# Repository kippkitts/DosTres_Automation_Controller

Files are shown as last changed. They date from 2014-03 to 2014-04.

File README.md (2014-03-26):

DosTres_Automation_Controller
=============================

DosTres Automation

The [DosTres Automation Controller](http://kippkitts.com/collections/frontpage/products/dostres-automation-controller-kk-m-23) is a shield for the Arduino Uno that allows you to control a number of high power devices.  It carries motor drivers to power 2 brush DC motors at 40v/5A as well as 3 MOSFET load switches to control high load devices (solenoids, lights, pumps, etc.).  The DosTres also allows you to drive a stepper motor in place of the DC motors.  The Eagle files for this board can be found here.

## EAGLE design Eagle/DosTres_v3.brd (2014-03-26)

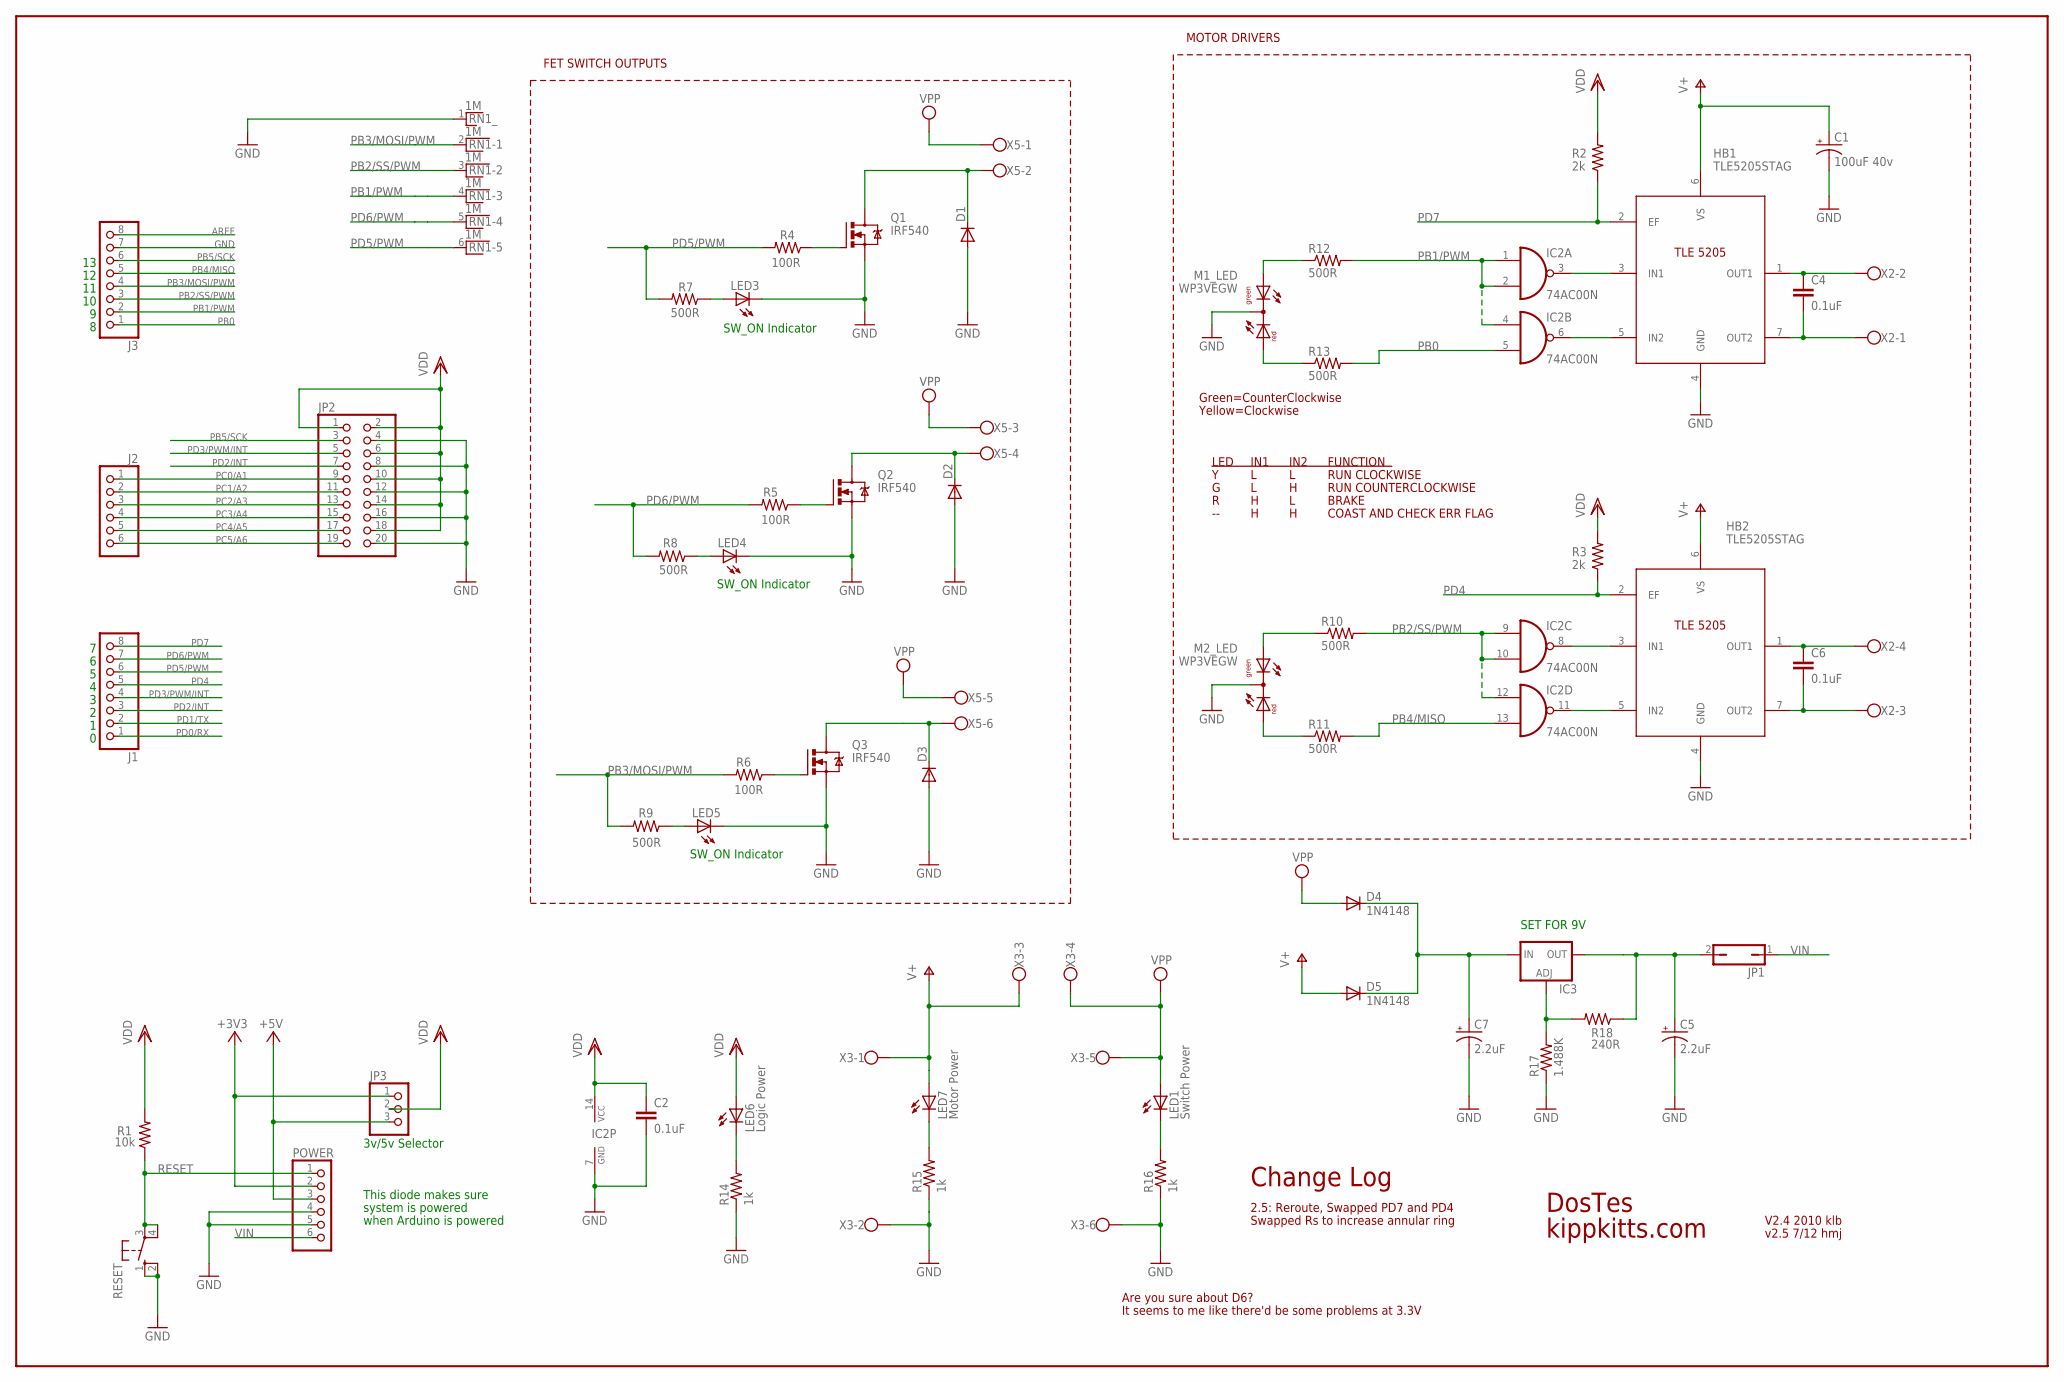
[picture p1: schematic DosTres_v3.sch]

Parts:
C1: 100uF 40v; E2,5-6E
C2, C4, C6: 0.1uF; CAP-PTH-SMALL-KIT
C5, C7: 2.2uF; CPOL-RADIAL-10UF-25V
D1, D2, D3: DIODE-1MMHOLED-7.5BH; D-7.5BH
D4, D5: 1N4148; D-7.5BH
HB1, HB2: TLE5205STAG; TO220-7-11
IC2: 74AC00N; DIL14
IC3: LM317TS; 317TS
J1, J3: PINHD-1X8; 1X08
J2: PINHD-1X6; 1X06
JP1: JP1Q; JP1
JP2: PINHD-2X10HAND; 2X10HAND
JP3: PINHD-1X3; 1X03
LED1: Switch Power; LED3MM
LED3, LED4, LED5: LED3MMX1MM3MM; LED3MM
LED6: Logic Power; LED3MM
LED7: Motor Power; LED3MM
M1_LED, M2_LED: WP3VEGW; DUOLED-A-3MM
POWER: PINHD-1X6; 1X06
Q1, Q2, Q3: IRF540; TO220BV
R1: 10k; 0207/2V
R2, R3: 2k; 0207/2V
R4, R5, R6: 100R; 0207/2V
R7, R8, R9, R10, R11, R12, R13: 500R; 0207/2V
R14, R15, R16: 1k; 0207/2V
R17: 1.488K; 0207/2V
R18: 240R; 0207/2V
RESET: 10-XX; B3F-10XX
RN1: 1M; RN-6
X2: W237-4
X3, X5: W237-6

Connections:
+3V3: JP3.1, POWER.2
+5V: JP3.3, POWER.3
AREF: J3.8
GND: C1.-, C2.2, C5.2 (-), C7.2 (-), D1.A, D2.A, D3.A, HB1.4 (GND), HB2.4 (GND), IC2.7 (GND), J3.7, JP2.4, JP2.8, JP2.12, JP2.16, JP2.20, LED3.K (C), LED4.K (C), LED5.K (C), M1_LED.2 (C), M2_LED.2 (C), POWER.4, POWER.5, Q1.S, Q2.S, Q3.S, R14.1, R15.1, R16.1, R17.1, RESET.1 (S), RESET.2 (S1), RN1.1, X3.2, X3.6
M1.1: C4.1, HB1.1 (OUT1), X2.2
M1.2: C4.2, HB1.7 (OUT2), X2.1
M2.1: C6.1, HB2.1 (OUT1), X2.4
M2.2: C6.2, HB2.7 (OUT2), X2.3
unnamed: Q1.G, R4.1
unnamed: Q2.G, R5.1
unnamed: Q3.G, R6.1
unnamed: M1_LED.3 (AG), R12.1
unnamed: HB1.3 (IN1), IC2.3 (O)
unnamed: HB1.5 (IN2), IC2.6 (O)
unnamed: HB2.3 (IN1), IC2.8 (O)
unnamed: HB2.5 (IN2), IC2.11 (O)
unnamed: M1_LED.1 (AR), R13.1
unnamed: D3.C, Q3.D, X5.6
unnamed: D2.C, Q2.D, X5.4
unnamed: M2_LED.1 (AR), R11.1
unnamed: M2_LED.3 (AG), R10.1
unnamed: D1.C, Q1.D, X5.2
unnamed: C7.1 (+), D4.C, D5.C, IC3.3 (IN)
unnamed: LED3.A, R7.1
unnamed: LED4.A, R8.1
unnamed: LED5.A, R9.1
unnamed: C5.1 (+), IC3.2 (OUT), JP1.2, R18.1
unnamed: IC3.1 (ADJ), R17.2, R18.2
unnamed: LED6.K (C), R14.2
unnamed: LED7.K (C), R15.2
unnamed: LED1.K (C), R16.2
PB0: IC2.5 (I1), J3.1, R13.2
PB1/PWM: IC2.1 (I0), IC2.2 (I1), IC2.4 (I0), J3.2, R12.2, RN1.4
PB2/SS/PWM: IC2.9 (I0), IC2.10 (I1), IC2.12 (I0), J3.3, R10.2, RN1.3
PB3/MOSI/PWM: J3.4, R6.2, R9.2, RN1.2
PB4/MISO: IC2.13 (I1), J3.5, R11.2
PB5/SCK: J3.6, JP2.3
PC0/A1: J2.1, JP2.9
PC1/A2: J2.2, JP2.11
PC2/A3: J2.3, JP2.13
PC3/A4: J2.4, JP2.15
PC4/A5: J2.5, JP2.17
PC5/A6: J2.6, JP2.19
PD0/RX: J1.1
PD1/TX: J1.2
PD2/INT: J1.3, JP2.7
PD3/PWM/INT: J1.4, JP2.5
PD4: HB2.2 (EF), J1.5, R3.1
PD5/PWM: J1.6, R4.2, R7.2, RN1.6
PD6/PWM: J1.7, R5.2, R8.2, RN1.5
PD7: HB1.2 (EF), J1.8, R2.1
RESET: POWER.1, R1.1, RESET.3, RESET.4 (P1)
V+: C1.+, D5.A, HB1.6 (VS), HB2.6 (VS), LED7.A, X3.1, X3.3
VDD: C2.1, IC2.14 (VCC), JP2.1, JP2.2, JP2.6, JP2.10, JP2.14, JP2.18, JP3.2, LED6.A, R1.2, R2.2, R3.2
VIN: JP1.1, POWER.6
VPP: D4.A, LED1.A, X3.4, X3.5, X5.1, X5.3, X5.5

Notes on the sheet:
Green=CounterClockwise
Yellow=Clockwise
SET FOR 9V
3v/5v Selector
SW_ON Indicator
This diode makes sure
when Arduino is powered
FET SWITCH OUTPUTS
IN1
IN2
FUNCTION
RUN CLOCKWISE
RUN COUNTERCLOCKWISE
BRAKE
COAST AND CHECK ERR FLAG
LED
MOTOR DRIVERS
system is powered
2.5: Reroute, Swapped PD7 and PD4
Change Log
DosTes
kippkitts.com
v2.5 7/12 hmj
Swapped Rs to increase annular ring
V2.4 2010 klb
Are you sure about D6?
It seems to me like there'd be some problems at 3.3V

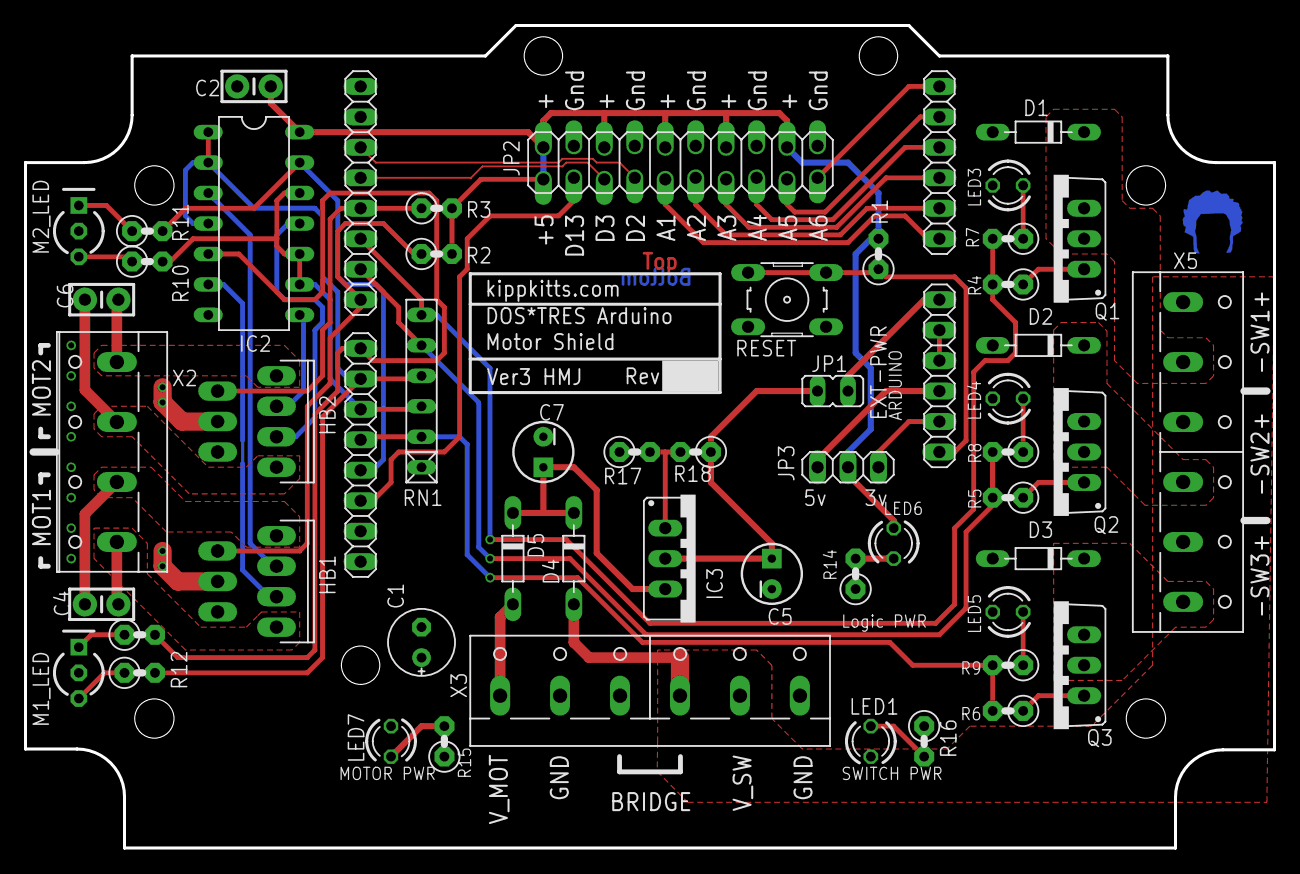
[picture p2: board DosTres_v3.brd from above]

Board: 2 copper layers, 104.1 x 68.6 mm, 58 parts (1 on the bottom side), 53 nets.

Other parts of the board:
U$1: TOP_DOCU_5MM
U$3: COPPER_5MM

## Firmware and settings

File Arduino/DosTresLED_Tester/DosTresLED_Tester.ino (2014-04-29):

/*
  Analog input, analog output, serial output
 
 Reads an analog input pin, maps the result to a range from 0 to 255
 and uses the result to set the pulsewidth modulation (PWM) of an output pin.
 Also prints the results to the serial monitor.
 

 */
const int analogOutPinR = 6; // Analog output pin that the LED is attached to
const int analogOutPinG = 5; // Analog output pin that the LED is attached to
const int analogOutPinB = 11; // Analog output pin that the LED is attached to

// 8,9,10,12 as outputs
const int motoPin1 = 8;
const int motoPin2 = 9;
const int motoPin3 = 10;
const int motoPin4 = 12;

const int mydelay = 4;

int outputValueR = 0;        // value output to the PWM (analog out)
int outputValueG = 0;        // value output to the PWM (analog out)
int outputValueB = 0;        // value output to the PWM (analog out)

int max_bright = 50;
int incomingByte = 0;	// for incoming serial data


void setup() {
  pinMode(motoPin1, INPUT);      // sets the digital pin as output
  pinMode(motoPin2, INPUT);      // sets the digital pin as output
  pinMode(motoPin3, INPUT);      // sets the digital pin as output
  pinMode(motoPin4, INPUT);      // sets the digital pin as output
  
  digitalWrite(motoPin1, HIGH);       // turn on pullup resistors
  digitalWrite(motoPin2, HIGH);       // turn on pullup resistors
  digitalWrite(motoPin3, HIGH);       // turn on pullup resistors
  digitalWrite(motoPin4, HIGH);       // turn on pullup resistors

   analogWrite(analogOutPinR, outputValueR);        
   analogWrite(analogOutPinB, outputValueB);           
   analogWrite(analogOutPinG, outputValueG);           


  // initialize serial communications at 9600 bps:
  Serial.begin(38400); 
}

void loop() {
// 
//  while(outputValueR < max_bright)
//  {
//    analogWrite(analogOutPinR, outputValueR);        
//    delay(mydelay);      
//    outputValueR = outputValueR + 1;
//  }
//  while(outputValueR > 0)
//  {
//    analogWrite(analogOutPinR, outputValueR);           
//    delay(mydelay);      
//    outputValueR = outputValueR - 1;
//  }
//    outputValueR = 0;
//    analogWrite(analogOutPinR, outputValueR);           
//   
// 	// send data only when you receive data:
//    while(Serial.available() == 0);
//    // read the incoming byte:
//    incomingByte = Serial.read();
//    Serial.flush();
//   

  while(outputValueR < max_bright)
  {
    analogWrite(analogOutPinR, outputValueR);        
    delay(mydelay);      
    outputValueR = outputValueR + 1;
  }
  while(outputValueR > 0)
  {
    analogWrite(analogOutPinR, outputValueR);           
    delay(mydelay);      
    outputValueR = outputValueR - 1;
  }
    outputValueR = 0;
    analogWrite(analogOutPinR, outputValueR);     
   
  while(outputValueG < max_bright)
  {
    analogWrite(analogOutPinG, outputValueG);           
    delay(mydelay);      
    outputValueG = outputValueG + 1;
  }
  while(outputValueG > 0)
  {
    analogWrite(analogOutPinG, outputValueG);           
    delay(mydelay);      
    outputValueG = outputValueG - 1;
  }
    outputValueG = 0;
    analogWrite(analogOutPinG, outputValueG);           

  while(outputValueB < max_bright)
  {
    analogWrite(analogOutPinB, outputValueB);           
    delay(mydelay);      
    outputValueB = outputValueB + 1;
  }
  while(outputValueB > 0)
  {
    analogWrite(analogOutPinB, outputValueB);           
    delay(mydelay);      
    outputValueB = outputValueB - 1;
  }
    outputValueB = 0;
    analogWrite(analogOutPinB, outputValueB);           


}

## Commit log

2014-03-26 Create Repository
    [DosTres_v3.brd, DosTres_v3.sch]
2014-04-29 Upload Arduino Code

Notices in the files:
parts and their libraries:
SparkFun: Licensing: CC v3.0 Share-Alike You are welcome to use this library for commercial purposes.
